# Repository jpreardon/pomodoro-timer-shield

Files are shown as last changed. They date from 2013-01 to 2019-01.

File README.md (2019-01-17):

Pomodoro Timer Shield for Arduino
=================================

This is a Pomodoro Timer, implemented  as an Arduino shield. The source code, schematic and board layout (in Eagle) are all included in this repository. For more information about the project, visit http://jpreardon.com/projects/pomodoro-timer/

© Copyright 2012-2019 John P. Reardon
Licensed under the MIT license.

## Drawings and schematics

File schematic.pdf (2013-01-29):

# +5VGND

# JP3 ¹²³⁴⁵⁶⁷⁸

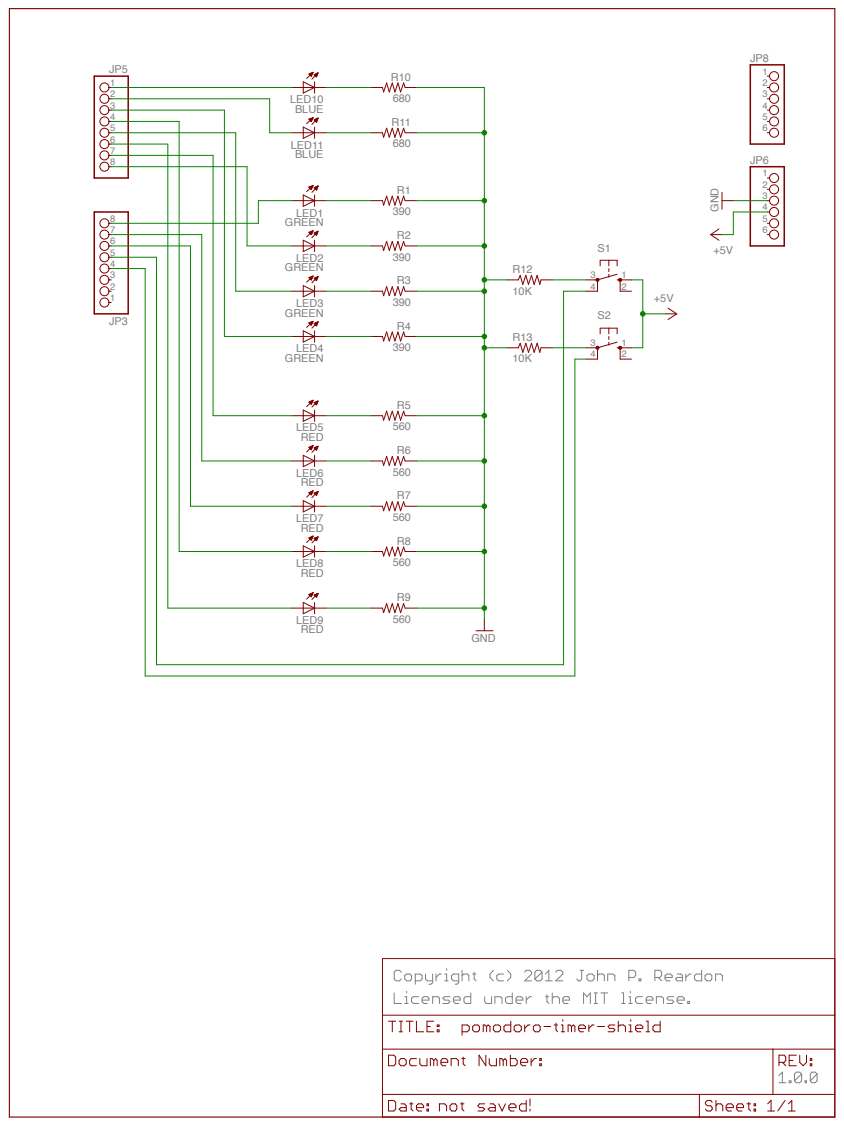
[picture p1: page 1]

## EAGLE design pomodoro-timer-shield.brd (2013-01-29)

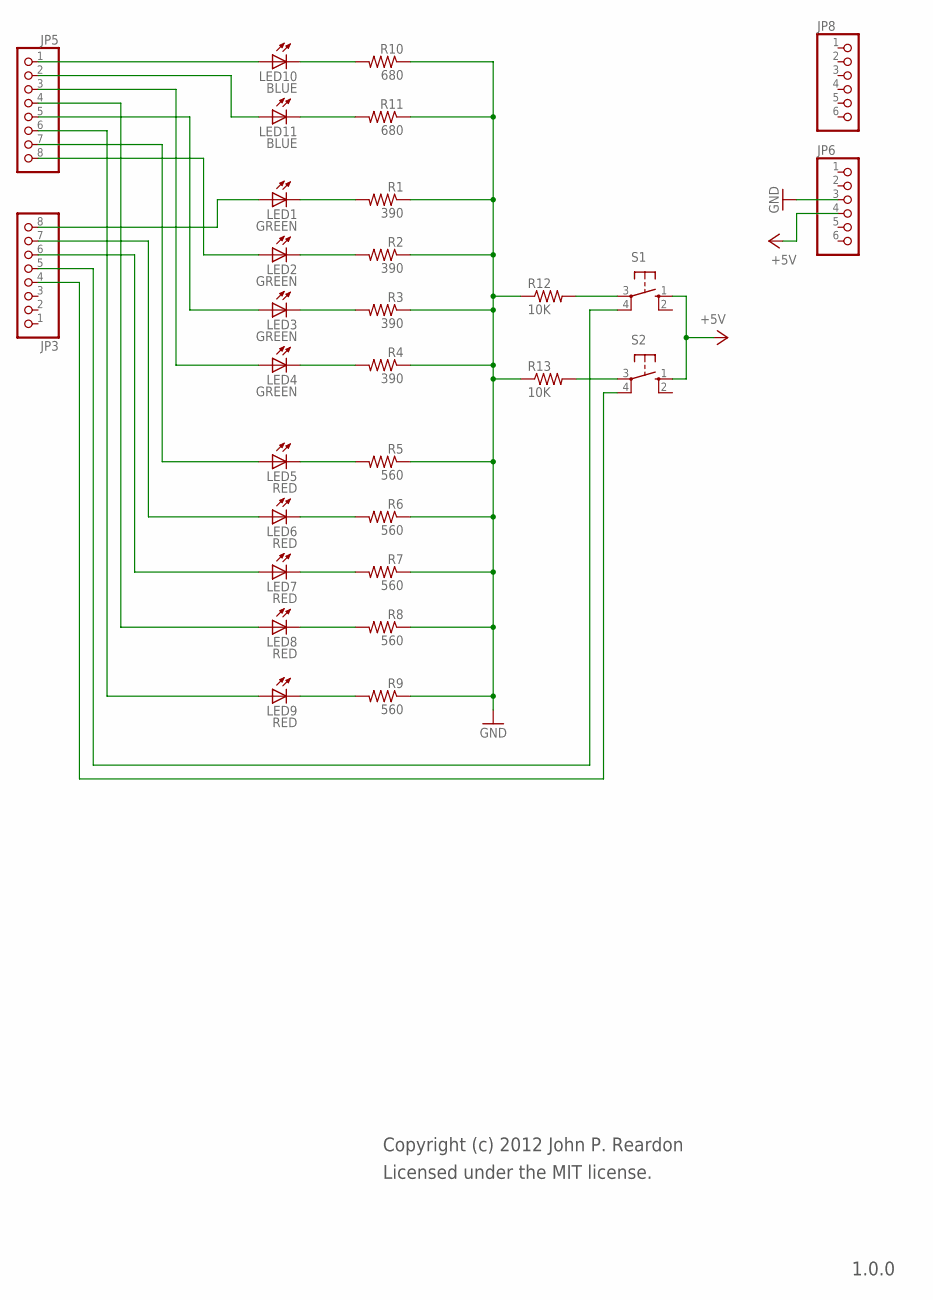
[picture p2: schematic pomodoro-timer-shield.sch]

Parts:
JP3, JP5: PINHD-1X8CLEANBIG; 1X08-CLEANBIG
JP6, JP8: PINHD-1X6CB; 1X06-CLEANBIG
LED1, LED2, LED3, LED4: GREEN; LED3MM
LED5, LED6, LED7, LED8, LED9: RED; LED3MM
LED10, LED11: BLUE; LED3MM
R1, R2, R3, R4: 390; 0204/7
R5, R6, R7, R8, R9: 560; 0204/7
R10, R11: 680; 0204/7
R12, R13: 10K; 0204/7
S1, S2: 10-XX; B3F-10XX

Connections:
+5V: JP6.4, S1.1 (S), S2.1 (S)
GND: JP6.3, R1.1, R2.1, R3.1, R4.1, R5.1, R6.1, R7.1, R8.1, R9.1, R10.1, R11.1, R12.1, R13.1
unnamed: JP5.1, LED10.A
unnamed: LED10.K (C), R10.2
unnamed: LED11.K (C), R11.2
unnamed: LED5.K (C), R5.2
unnamed: LED4.K (C), R4.2
unnamed: LED8.K (C), R8.2
unnamed: LED3.K (C), R3.2
unnamed: LED2.K (C), R2.2
unnamed: LED1.K (C), R1.2
unnamed: LED7.K (C), R7.2
unnamed: LED6.K (C), R6.2
unnamed: LED9.K (C), R9.2
unnamed: R12.2, S1.3
unnamed: R13.2, S2.3
unnamed: JP3.5, S1.4 (P1)
unnamed: JP3.4, S2.4 (P1)
unnamed: JP5.2, LED11.A
unnamed: JP3.8, LED1.A
unnamed: JP5.8, LED2.A
unnamed: JP5.7, LED5.A
unnamed: JP5.5, LED3.A
unnamed: JP5.3, LED4.A
unnamed: JP3.7, LED6.A
unnamed: JP3.6, LED7.A
unnamed: JP5.4, LED8.A
unnamed: JP5.6, LED9.A

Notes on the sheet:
Licensed under the MIT license.
1.0.0
Copyright (c) 2012 John P. Reardon

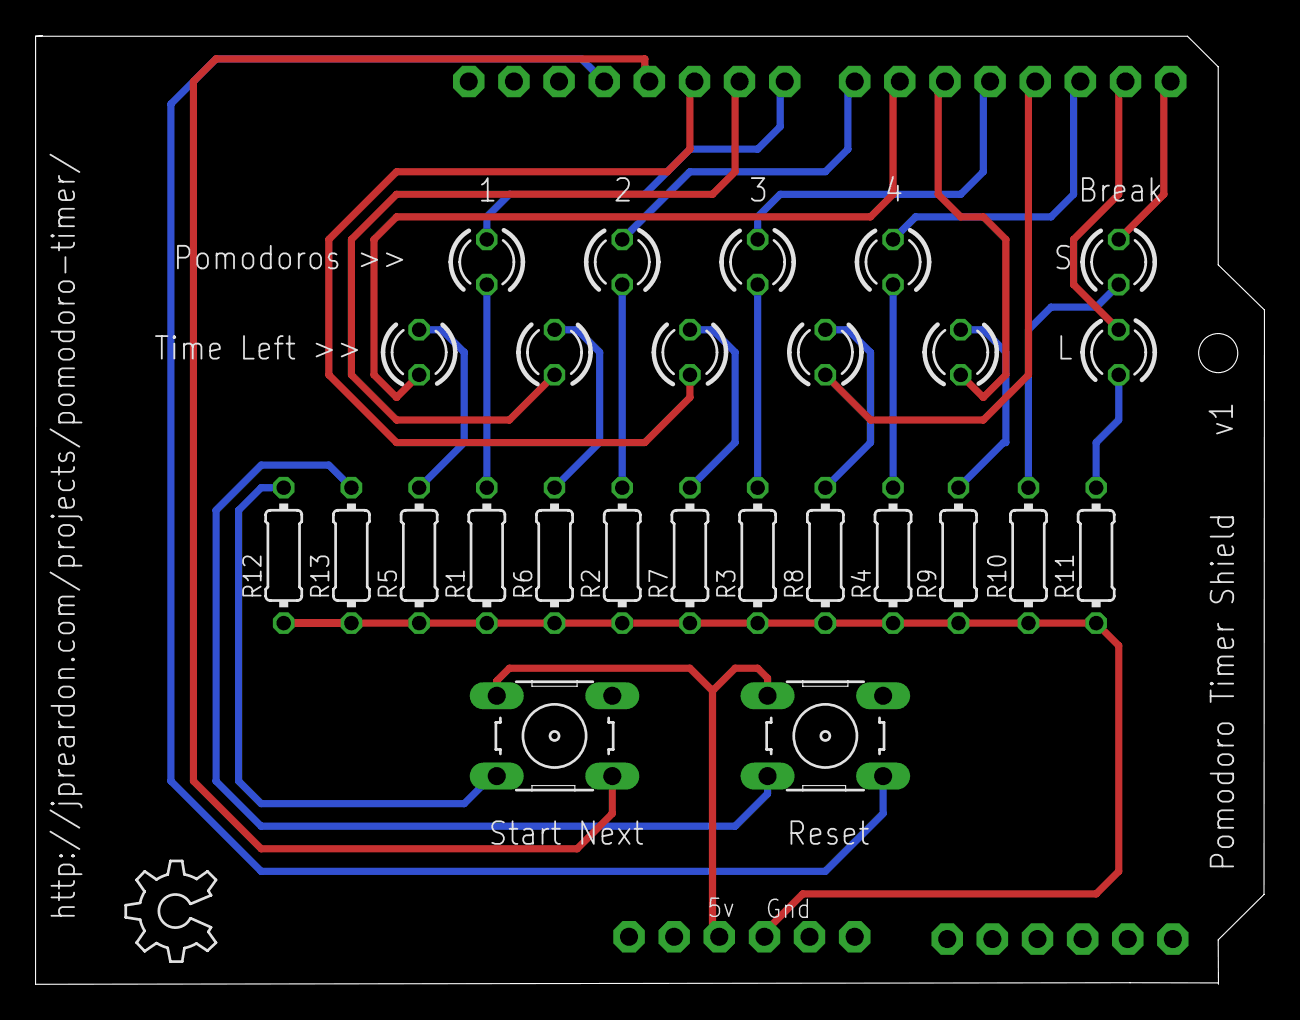
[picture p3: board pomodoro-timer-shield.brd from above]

Board: 2 copper layers, 69.2 x 53.4 mm, 31 parts (0 on the bottom side), 28 nets.

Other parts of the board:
U$2: OSHW_6X200_NOTEXT

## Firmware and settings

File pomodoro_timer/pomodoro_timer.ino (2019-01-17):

/*
  Project Name: Pomorodo Timer Shield
  Created: 2012-12-27
  By: John P. Reardon <jp@jpreardon.com>
  Version: 1.0.0 (2013-01-28)
  Version: 1.0.1 (2019-01-16)

  This is a simple timer shield that can be used to practice the Pomodoro Technique®. For
  a schematic and board layout visit this site http://jpreardon.com/projects/pomodoro-timer/
  
  For more on the Pomodoro Technique®, check out this site http://www.pomodorotechnique.com

  © Copyright 2012-2019 John P. Reardon
  Licensed under the MIT license.
  
*/

// Define debug state (1 for debug, 0 for not)
#define DEBUG 0

// Define available modes
#define IDLE 1
#define SHORT_BREAK 2
#define LONG_BREAK 3
#define POMODORO 4
#define IN_PROCESS 5

// Constants for input/output pins
const int greenLed1 = 8;   // Green LEDs are for the pomodoro count
const int greenLed2 = 7;
const int greenLed3 = 4;
const int greenLed4 = 2;  
const int redLed1 = 6;     // Red LEDs count the time left
const int redLed2 = 9;     // in a pomodoro, or a break
const int redLed3 = 10;    // They need to be connected to PWM pins
const int redLed4 = 3;
const int redLed5 = 5;
const int blueLed1 = 0;    // Short break indicator
const int blueLed2 = 1;    // Long break indicator
const int button1 = 11;    // Start/Interrupt
const int button2 = 12;    // Reset

// Constants for time values (in minutes)
const int pomodoroTime = 25;  // Should be 25
const int shortBreakTime = 5; // Should be 5
const int longBreakTime = 15; // Should be 15

// Fields to hold state
int currentMode = IDLE;    // Values are IDLE, SHORT_BREAK, LONG_BREAK, POMODORO, IN_PROCESS
int nextMode = POMODORO;   // Holds the next mode
int currentPomodoroCount;  // Number of completed pomodoros
long stateStartTime;       // In milliseconds
int modeFinished = 0;      // To let us know if the last pomodoro or break was completed

// LED Display variables
// Blinky
int ledState = LOW;         // This will be used if a LED needs to blink
int blinkInterval = 1000;   // In milliseconds
long previousMillis = 0;    // Last time the LED was updated

//Fade
int ledFadeAmount = 1;                  // The amount to fade the LED(s)
int minLedBrightness = 5;               // The minimum value for fading
int maxLedBrightness = 50;              // Maximum brightness value for lit LEDs (50)
int maxLedFadeBrightness = 50;          // Fading LEDs are a little dimmer
int ledBrightness = minLedBrightness;   // The current brightness of the LED(s)
int fadeInterval = 1000;                // In milliseconds, the amount of time for fade cycle
long previousFadeMillis = 0;            // Last time the fade LED was updated

void setup() {
  if (DEBUG) Serial.begin(9600);
  
  // Set pins to the proper mode
  pinMode(greenLed1, OUTPUT);
  pinMode(greenLed2, OUTPUT);
  pinMode(greenLed3, OUTPUT);
  pinMode(greenLed4, OUTPUT);
  pinMode(redLed1, OUTPUT);
  pinMode(redLed2, OUTPUT);
  pinMode(redLed3, OUTPUT);
  pinMode(redLed4, OUTPUT);
  pinMode(redLed5, OUTPUT);
  pinMode(blueLed1, OUTPUT);
  pinMode(blueLed2, OUTPUT);
  pinMode(button1, INPUT);
  pinMode(button2, INPUT);
}

void loop() {
  // Check to see if buttons are pressed
  checkButtons();
  
  // Increment Everything
  incrementTime();
  
  // Display current state
  displayState();
}

// Check the buttons to see if one of them is pressed
void checkButtons() {
  // See if any button are pressed, if they are, do something
  
  if(digitalRead(button2) == HIGH) {
    // debounce, ignore any button presses one second after a state change
    if ((millis() - stateStartTime) < 1000) {
      return;
    }
    // full reset
    setCurrentMode(IDLE);
    modeFinished = 0;
    resetPomodoroCount();
    if (DEBUG) Serial.println("RESET!");
  }
  
  if(digitalRead(button1) == HIGH) {
    // debounce, ignore any button presses one second after a state change
    if ((millis() - stateStartTime) < 1000) {
      return;
    }
    
    switch (currentMode) {
      case IDLE:
        resetPomodoroCount();
        modeFinished = 0;
        setCurrentMode(POMODORO);
        nextMode = SHORT_BREAK;
        if (DEBUG) Serial.println("changing to pomodoro mode");
        break;
      case SHORT_BREAK:
        setCurrentMode(IN_PROCESS);
        nextMode = POMODORO;
        if (DEBUG) Serial.println("changing to in process mode from short break");
        break;
      case LONG_BREAK:
        resetPomodoroCount();
        setCurrentMode(IDLE);
        if (DEBUG) Serial.println("changing to idle mode from long break");
        break;
      case POMODORO:
        setCurrentMode(IN_PROCESS);
        nextMode = POMODORO;  
        if (DEBUG) Serial.println("changing to in process mode from pomodoro");
        break;
      case IN_PROCESS:
        setCurrentMode(nextMode);
        modeFinished = 0;
        if (DEBUG) Serial.print("changing from in process to next mode: ");
        if (DEBUG) Serial.println(nextMode);
        break;
    }
  }
}

// This is the function that will set the proper state when the time has elapsed
// for a given mode.
void incrementTime() {
  
  unsigned long currentMillis = millis();
  
  // Increment the timer, see if the state needs to change
  switch (currentMode) {
    case IDLE:
      // Idle mode, do nothing
      break;
    case SHORT_BREAK:
      // short break code here
      // If break is over, change modes
      if(currentMillis - stateStartTime > convertMinuteToMillis(shortBreakTime)){
        setCurrentMode(IN_PROCESS);
        nextMode = POMODORO;
        modeFinished = 1;
      }
      break;
    case LONG_BREAK:
      // long break code here
      if(currentMillis - stateStartTime > convertMinuteToMillis(longBreakTime)){
        setCurrentMode(IDLE);
        nextMode = POMODORO;
        modeFinished = 1;
      }
      break;
    case POMODORO:
      // pomodoro code here
      if(currentMillis - stateStartTime > convertMinuteToMillis(pomodoroTime)){
        currentPomodoroCount++;
        modeFinished = 1;
        if (currentPomodoroCount == 4) {
          setCurrentMode(IN_PROCESS);
          nextMode = LONG_BREAK;
        } else {
          setCurrentMode(IN_PROCESS);
          nextMode = SHORT_BREAK;
        }
      }
      break;
    case IN_PROCESS:
      // do nothing
    default:
      // do nothing
      break;
  }
 
}

// This function displays the current state
void displayState() {
  
  unsigned long currentMillis = millis();
  unsigned long millisPassed;
  float numLeds;
  
  // We always light the proper number of pomodoro number lights, unless the state is idle
  if (currentMode != IDLE) {
    lightGreenLeds(currentPomodoroCount);
  }
  
  // Light up leds based on the current state
  switch (currentMode) {
    case IDLE:
      // If we reached the end of the pomodoro cycle, blink the green leds
      if (modeFinished) {
        blinkGreenLeds();
      } 
      else {
        turnAllOff();
      }
      break;
    case SHORT_BREAK:
      // We're on a break, light a break light
      digitalWrite(blueLed1, HIGH);
      // Figure out how much time has passed
      millisPassed = currentMillis - stateStartTime;
      // Figure out how many LEDs to light up, cast a variable as a float so we get a float back
      numLeds = ((float)shortBreakTime - convertMillisToMinute(millisPassed)) / (shortBreakTime / 5); 
      // Light em up
      lightRedLeds(numLeds);
      break;
    case LONG_BREAK:
      // We're on a break, light a break light
      digitalWrite(blueLed2, HIGH);
      // Figure out how much time has passed
      millisPassed = currentMillis - stateStartTime;
      // Figure out how many LEDs to light up, cast a variable as a float so we get a float back
      numLeds = ((float)longBreakTime - convertMillisToMinute(millisPassed)) / (longBreakTime / 5);
      // Light em up
      lightRedLeds(numLeds);
      break;
    case POMODORO:
      // Turn off the break lights
      digitalWrite(blueLed1, LOW);
      digitalWrite(blueLed2, LOW);
      // Figure out how much time has passed
      millisPassed = currentMillis - stateStartTime;
      // Figure out how many LEDs to light up, cast a variable as a float so we get a float back
      numLeds = ((float)pomodoroTime - convertMillisToMinute(millisPassed)) / (pomodoroTime / 5);
      // Light em up
      lightRedLeds(numLeds);
      break;
    case IN_PROCESS:
      if (modeFinished) {
        blinkRedLeds();
      }
      else {
        lightRedLeds(0);
      }
      break;
    default:
      // Do nothing
      break;
  }
  
}

// Blink the red LEDs
void blinkRedLeds() {
  analogWrite(redLed1, fadeLed());
  analogWrite(redLed2, fadeLed());
  analogWrite(redLed3, fadeLed());
  analogWrite(redLed4, fadeLed());
  analogWrite(redLed5, fadeLed());
}

// Blink the green LEDs
void blinkGreenLeds() {
  digitalWrite(greenLed1, blinkLed());
  digitalWrite(greenLed2, blinkLed());
  digitalWrite(greenLed3, blinkLed());
  digitalWrite(greenLed4, blinkLed());
}

// Light the number of red LEDs specified
// With a nice fade
void lightRedLeds(float numLeds) {
  if (numLeds > 4) {
    analogWrite(redLed1, maxLedBrightness);
    analogWrite(redLed2, maxLedBrightness);
    analogWrite(redLed3, maxLedBrightness);
    analogWrite(redLed4, maxLedBrightness);
    analogWrite(redLed5, fadeLed());
  }
  else if (numLeds > 3) {
    analogWrite(redLed1, maxLedBrightness);
    analogWrite(redLed2, maxLedBrightness);
    analogWrite(redLed3, maxLedBrightness);
    analogWrite(redLed4, fadeLed());
    analogWrite(redLed5, LOW);
  }
  else if (numLeds > 2) {
    analogWrite(redLed1, maxLedBrightness);
    analogWrite(redLed2, maxLedBrightness);
    analogWrite(redLed3, fadeLed());
    analogWrite(redLed4, LOW);
    analogWrite(redLed5, LOW);
  }
  else if (numLeds > 1) {
    analogWrite(redLed1, maxLedBrightness);
    analogWrite(redLed2, fadeLed());
    analogWrite(redLed3, LOW);
    analogWrite(redLed4, LOW);
    analogWrite(redLed5, LOW);  
  }
 else if (numLeds > 0) {
     analogWrite(redLed1, fadeLed());
     analogWrite(redLed2, LOW);
     analogWrite(redLed3, LOW);
     analogWrite(redLed4, LOW);
     analogWrite(redLed5, LOW);
 }
 else {
     analogWrite(redLed1, LOW);
     analogWrite(redLed2, LOW);
     analogWrite(redLed3, LOW);
     analogWrite(redLed4, LOW);
     analogWrite(redLed5, LOW);
 }
}

// Light the number of green LEDs specified
void lightGreenLeds(int numLeds) {
    switch (numLeds) {
    case 1:
      digitalWrite(greenLed1, HIGH);
      digitalWrite(greenLed2, LOW);
      digitalWrite(greenLed3, LOW);
      digitalWrite(greenLed4, LOW);
      break;
    case 2:
      digitalWrite(greenLed1, HIGH);
      digitalWrite(greenLed2, HIGH);
      digitalWrite(greenLed3, LOW);
      digitalWrite(greenLed4, LOW);
      break;
    case 3:
      digitalWrite(greenLed1, HIGH);
      digitalWrite(greenLed2, HIGH);
      digitalWrite(greenLed3, HIGH);
      digitalWrite(greenLed4, LOW);
      break;
    case 4:
      digitalWrite(greenLed1, HIGH);
      digitalWrite(greenLed2, HIGH);
      digitalWrite(greenLed3, HIGH);
      digitalWrite(greenLed4, HIGH);
      break;
    default:
      digitalWrite(greenLed1, LOW);
      digitalWrite(greenLed2, LOW);
      digitalWrite(greenLed3, LOW);
      digitalWrite(greenLed4, LOW);
  }
}
 
// Should a blinky LED be lit or not? Returns a HIGH or LOW value based on time
int blinkLed() {
  unsigned long currentMillis = millis();
  
  if (currentMillis - previousMillis > blinkInterval) {
    
    previousMillis = currentMillis;
    
    if (ledState == LOW) {
      ledState = HIGH;
    } else {
      ledState = LOW;
    }
  }
  return ledState;
}

// Returns a fade value
int fadeLed() {
  unsigned long currentMillis = millis();
  
  if ((currentMillis - previousFadeMillis) > fadeInterval / ((maxLedFadeBrightness - minLedBrightness) / abs(ledFadeAmount))) {
    ledBrightness = ledBrightness + ledFadeAmount;
    previousFadeMillis = currentMillis;
    if (ledBrightness == minLedBrightness || ledBrightness == maxLedFadeBrightness) {
      ledFadeAmount = -ledFadeAmount ; 
    } 
  }
  return ledBrightness;
}
 
void turnAllOn() {
 // You guessed it, turn all the lights on at once
 digitalWrite(greenLed1, HIGH);
 digitalWrite(greenLed2, HIGH);
 digitalWrite(greenLed3, HIGH);
 digitalWrite(greenLed4, HIGH);
 digitalWrite(redLed1, HIGH);
 digitalWrite(redLed2, HIGH);
 digitalWrite(redLed3, HIGH);
 digitalWrite(redLed4, HIGH);
 digitalWrite(redLed5, HIGH);
 digitalWrite(blueLed1, HIGH);
 digitalWrite(blueLed2, HIGH);
}

void turnAllOff() {
 // You guessed it, turn all the lights off at once
 digitalWrite(greenLed1, LOW);
 digitalWrite(greenLed2, LOW);
 digitalWrite(greenLed3, LOW);
 digitalWrite(greenLed4, LOW);
 digitalWrite(redLed1, LOW);
 digitalWrite(redLed2, LOW);
 digitalWrite(redLed3, LOW);
 digitalWrite(redLed4, LOW);
 digitalWrite(redLed5, LOW);
 digitalWrite(blueLed1, LOW);
 digitalWrite(blueLed2, LOW);
}

long convertMinuteToMillis(int minutes) {
  return minutes * 60000;
}

int convertMillisToMinute(long millis) {
  return millis / 60000;
}

// This sets the current mode
void setCurrentMode(int newMode) {
  currentMode = newMode;
  stateStartTime = millis();
}

void resetPomodoroCount() {
  currentPomodoroCount = 0;
}

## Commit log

2012-12-28 Started working on the blinky, and timer functions
2012-12-28 Fixed the timer LEDs light properly in relation to time left
    [pomodoro_timer.ino]
2012-12-31 Implemented fade instead of blink on for the timer LEDs
2013-01-01 Changed schematic for Arduino shield configuration
2013-01-29 Minor changes to the Arduino sketch (fade timing and comments), adding updated schematic, board layout and license. Updated readme
    [pomodoro-timer-shield.brd, pomodoro-timer-shield.sch]
